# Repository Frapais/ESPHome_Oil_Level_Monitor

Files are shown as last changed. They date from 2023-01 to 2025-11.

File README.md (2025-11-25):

<h1 align="center">
  <br>
  ESPHome Oil Level Sensor
  <br>
</h1>

<h4 align="center">A custom <a href="https://github.com/esphome/esphome" target="_blank">ESPHome</a> sensor for <a href="https://github.com/home-assistant" target="_blank">Home Assistant</a>.</h4>

<p align="center">
  <a href="https://saythanks.io/to/Frapais">
      
  </a>
  <a href="https://paypal.me/kostasparaskevas?country.x=GR&locale.x=en_US">
    
  </a>
</p>

<p align="center">
  <a href="#description">Description</a> •
  <a href="#hardware-components">Hardware Components</a> •
  <a href="#how-to-use">How To Use</a> •
  <a href="#download">Download</a> •
  <a href="#credits">Credits</a> •
  <a href="#related">Related</a> •
</p>

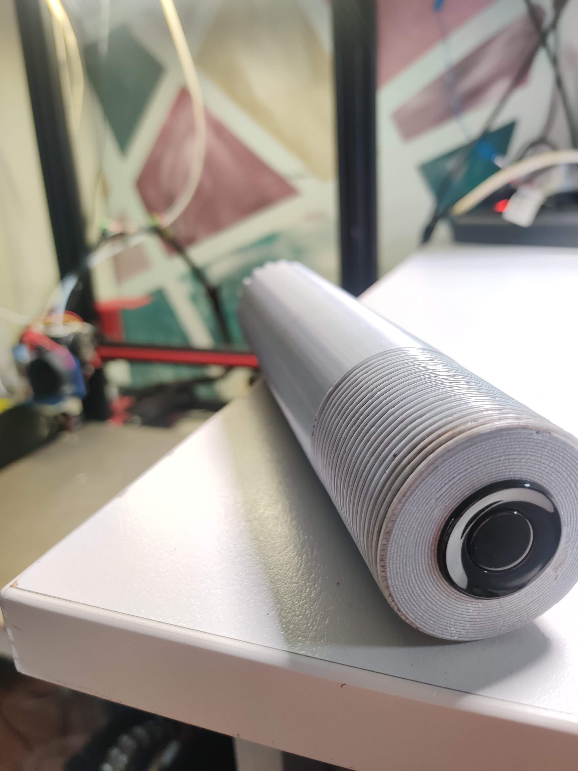
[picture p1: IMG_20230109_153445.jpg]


## Description
### Hardware description
This sensor uses an ESP32 board that supports battery power/charging. The ESP32 also measures the battery voltage via an analog pin, through a voltage divider. The voltage divired is needed because the maximum voltage of the battery is **4.2V** while the ADC of the ESP32 can measure only up to **1.1V**. 
The oil level measurement is done with a waterproof ultrasonic sensor and its module pcb. However, you can probably use a regular ultrasonic sensor. 
The electronics were mounted inside a custom enclosure that was designed to screw on the lid of my oil tank.
### How the measurement works
This sensor works using an Ultrasonic sensor, to measure the level of a liquid in a tank.
In this particular case, the sensor is placed at the top of the tank, pointing down on the surface of the liquid.
This way, we can measure the distance of the liquid from the top of the tank, and, knowing the dimensions of the tank, we can calculate its volume.
Specifically, we measure the volume of the remaining liquid using the following formula:
$$remainingVolume=maxVolume - measuredVolume$$

where *maxVolume* is calculated from the dimensions of the tank (*Length, Width, Height*), and *measuredVolume* is calculated using the following formula:
$$measuredVolume = Length * Width * measuredDistance$$

Similarly, the consumed liquid can be calculated using the following formula:
$$consumedVolume = measuredVolume  - (maxVolume - initialVolume)$$
where *initialVolume* is the volume of the liquid when we start the consumption measurement

### General code flow
* ESP wakes up for **60 seconds**
  * Connects to Home Assistant
  * Samples **17 times** the oil surface distance and calculates an average
  * Samples the battery voltage and converts it to **percentage**
  * Calculates and updates the **consumed oil volume** and the **remaining oil volume**
* Falls to deep sleep for **29 minutes**

## Hardware Components

* [ESP32](https://www.amazon.com/Adafruit-PID-3591-HUZZAH32-pre-soldered/dp/B079QGXX88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) board with battery charging capability
* Li-Ion battery
* [Waterproof](https://www.amazon.com/Waterproof-Ultrasonic-JSN-SR04T-Integrated-Transducer/dp/B07FQCNXPP) Ultrasonic sensor
* 2 resistors for measuring the battery voltage

## How To Use

You need to have a [Home Assistant](https://github.com/home-assistant) server with [ESPHome](https://github.com/esphome/esphome) plugin working.
If so, follow these steps:

* Connect the hardware components according to the [schematic](https://github.com/Frapais/ESPHome_Oil_Level_Monitor/blob/main/Rough%20schematic.png)
* Download the YAML code for this sensor and make the required changes in the parameters according to your use-case
* Create a new sensor in your ESPHome dashboard
* Copy your customized YAML code to the sensor's YAML code
* Download and 3D print the [electronics enclosure](https://www.thingiverse.com/thing:5776524), or design your own according to your needs.

<!-- > **Note**
> If you're using Linux Bash for Windows, [see this guide](https://www.howtogeek.com/261575/how-to-run-graphical-linux-desktop-applications-from-windows-10s-bash-shell/) or use `node` from the command prompt. -->

## Download

* [YAML](https://github.com/Frapais/ESPHome_Oil_Level_Monitor/blob/main/fuel-level-sensor.yaml) code
* [3D files](https://github.com/Frapais/ESPHome_Oil_Level_Monitor/blob/main/Oil%20level%20sensor%20enclosure.stl)
* [schematic](https://github.com/Frapais/ESPHome_Oil_Level_Monitor/blob/main/Rough%20schematic.png)

## Credits

This software uses the following platforms:

- [Home Assistant](https://www.home-assistant.io/)
- [ESPHome](https://esphome.io/)

## Related

You can find similar code in the official Ultrasonic sensor implementation page of ESPHome
[Ultrasonic sensor](https://esphome.io/components/sensor/ultrasonic.html)

## Support

<a href="https://buymeacoffee.com/spriglabs" target="_blank">Buy Me A Coffee</a>

> YouTube [@Sprig Labs](https://www.youtube.com/@sprig_labs) &nbsp;&middot;&nbsp;
> Instagram [@Sprig Labs](https://www.instagram.com/sprig_labs/)

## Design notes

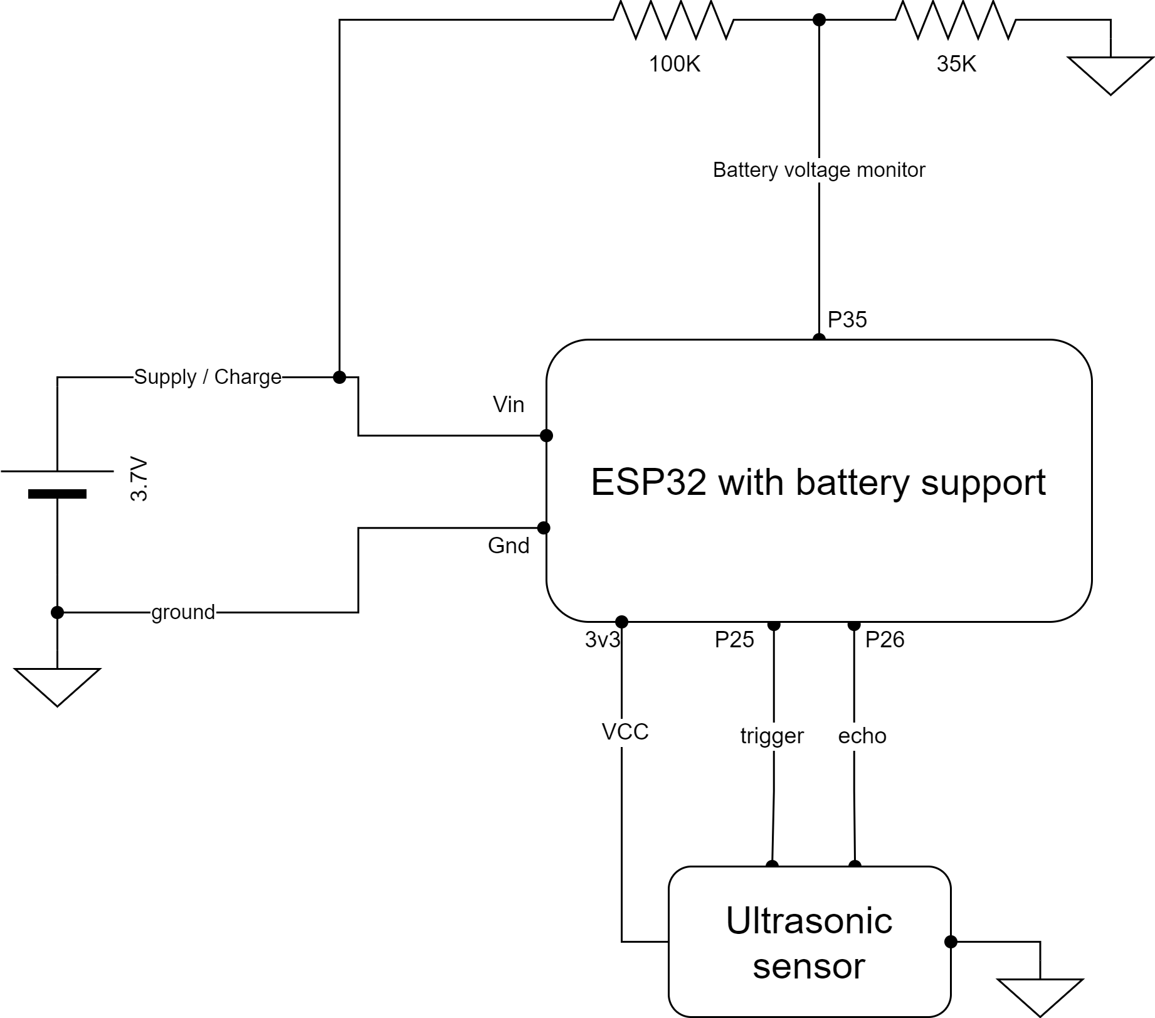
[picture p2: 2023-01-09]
Rough schematic.png

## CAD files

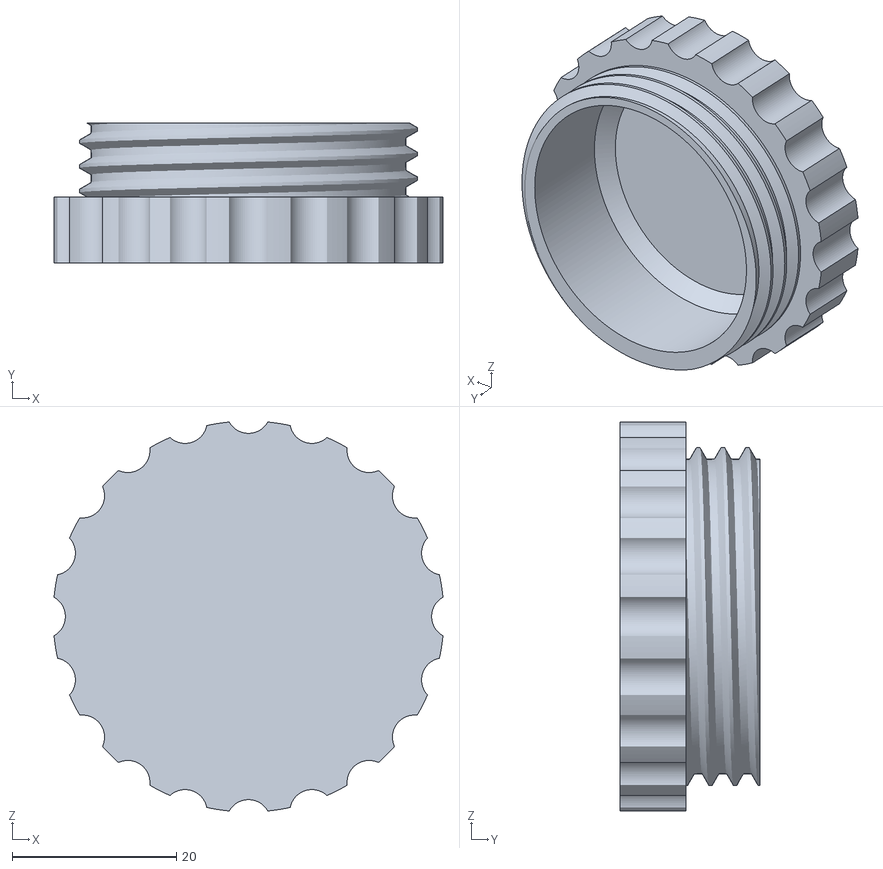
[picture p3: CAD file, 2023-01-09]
Oil level sensor cap.stl
47.4 x 17.0 x 47.4

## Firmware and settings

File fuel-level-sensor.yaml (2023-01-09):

esphome:
  name: "fuel-level-sensor"
  on_boot:
    then:
      - script.execute: deep_sleep_evaluation

esp32:
  board: esp32dev
  framework:
    type: arduino

# Enable logging
logger:

# Enable Home Assistant API
api:

ota:


wifi:
  ssid: !secret wifi_ssid
  password: !secret wifi_password

  # Enable fallback hotspot (captive portal) in case wifi connection fails
  ap:
    ssid: "---your ssid---"
    password: "---your password---"

captive_portal:

# Ultrasonic sensor configuration
# Since the wake up duration is 60s, the whole sampling process must take less than that.
# We sample the ultrasonic sensor 17 times, every 1s, and calculate an average using the "quantile" filter, taking 17s in total.
# So, we have 17s to sample and calculate the values, and 43s to establish WiFi connection after waking up.
sensor:
  - platform: ultrasonic
    trigger_pin: 25
    echo_pin: 26
    id: measured_distance
    accuracy_decimals: 4  # Using 4 decimal digits we can achieve 0.1L resolution 
    update_interval: 1000ms # You may change this value
    filters:
    # quantile filtering requires odd number of samples.
    - quantile:
        window_size: 17
        send_every: 17
        send_first_at: 17
        quantile: .9
  
  # Battery monitoring configuration
  - platform: adc
    pin: 35
    id: battery_percentage
    name: "Fuel level sensor Battery"
    update_interval: 17s
    filters:
      - calibrate_linear: # Convert analog read values to percentage
          # Map 0.0 (from sensor) to 0.0 (true value)
          - 0.73 -> 0
          - 1.022 -> 100
    unit_of_measurement: '%'
    accuracy_decimals: 0

  # Heating oil volume calculation configuration
  # Knowing the dimensions of the oil tank, we can calculate its volume,
  # thus, the distance measured by the ultrasonic sensor, gives us the volume of the empty-portion of the tank.
  # Knowing the initial volume of the oil (0.239 m³), the maximum volume of the tank (0.357 m³), and the measured volume by the sensor (measured_distance * length * width),
  # We can calculate the burned oil volume using the following formula:
  # burned oil volume = (measured_volume) - (max_volume - initial_volume)
  - platform: template
    id: burned_diesel
    name: "Burned diesel"
    device_class: gas
    state_class: "total_increasing"
    accuracy_decimals: 3
    lambda: return  id(measured_distance).state * 0.70 * 0.30 - (0.357-0.239);
    unit_of_measurement: 'm³'
    update_interval: 17s
  
  # Remaining oil volume calculation configuration
  # Similarly, we can calculate the remaining oil in the tank using the following formula:
  # remaining oil volume = max_volume - measured_volume
  # Only this time, the remaining volume is measured in Liters to make it easier to read.
  - platform: template
    id: remaining_diesel
    name: "Remaining diesel"
    accuracy_decimals: 1
    lambda: return  357.0 - (id(measured_distance).state * 0.70 * 0.30) * 1000;
    unit_of_measurement: 'L'
    update_interval: 17s        #You may change this value (in seconds)


          
# Deep sleep configuration
deep_sleep:
  id: deep_sleep_enabled
  sleep_duration: 29min

# This section reads a binary sensor in Home Assistant that disables deep sleep when pressed.
# It makes it easier to connect to the device and upload the code.
binary_sensor:
  - platform: homeassistant
    id: disable_deep_sleep
    entity_id: input_boolean.disable_deep_sleep

# Deep sleep implementation
# When this script is called, the device stays awake for 60s and calculates everything we mentioned above.
# Then, if deep sleep is enabled, it will go to sleep for the duration we set above.
script:
  - id: deep_sleep_evaluation
    mode: queued
    then:
      - delay: 60s
      - if:
          condition:
            binary_sensor.is_on: disable_deep_sleep
          then:
            - logger.log: 'Deep Sleep Disabled'
          else:
            - deep_sleep.enter: deep_sleep_enabled
      - script.execute: deep_sleep_evaluation

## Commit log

2023-01-09 Added main yaml file
    This is the code that runs on the esp32 board
2023-01-09 Electronics schematic diagram
    This is the rough schematic of the hardware.
    It consists of an ESP32 board that supports battery supply / charging, a 18650 li-ion battery, an ultrasonic sensor, and a voltage divider to monitor the battery's voltage.
2023-01-09 3D files of the enclosure
    It is an enclosure that screws directly into the tank's cap.
    [Oil level sensor cap.stl]
